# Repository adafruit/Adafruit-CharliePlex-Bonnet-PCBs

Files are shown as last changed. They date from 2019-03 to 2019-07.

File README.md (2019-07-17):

## Adafruit CharliePlex LED Matrix Bonnet PCB

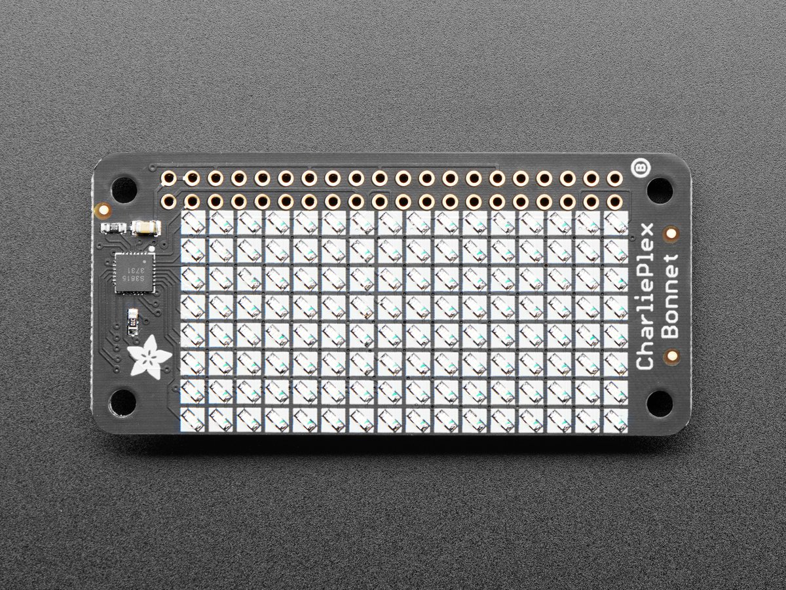
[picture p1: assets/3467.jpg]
<a href="http://www.adafruit.com/products/3467"><br/>
Click here to purchase one from the Adafruit shop</a>

PCB files for the Adafruit CharliePlex LED Matrix Bonnet. 

Format is EagleCAD schematic and board layout

* https://www.adafruit.com/?q=charlieplex%20bonnet

### Description

You won't be able to look away from the mesmerizing patterns created by this Adafruit CharliePlex LED Matrix Display Bonnet.  This 16x8 LED display can be placed atop any Raspberry Pi computer with a 2x20 connector, for a beautiful, bright grid of 128 charlieplexed LEDs. It even comes with a built-in charlieplex driver that is run over I2C.

We carry these Bonnets in a [few vivid colors](https://www.adafruit.com/?q=charlieplex%20bonnet)

What is particularly nice about this Wing is the I2C LED driver chip has the ability to PWM each individual LED in a 16x8 grid so you can have beautiful LED lighting effects, without a lot of pin twiddling. Simply tell the chip which LED on the grid you want lit, and what brightness and it's all taken care of for you. You get 8-bit (256 level) dimming for each individual LED.

The IS31FL3731 is a nice little chip - and it runs happily over 3.3V power. Inside is enough RAM for 8 separate frames of display memory so you can set up multiple frames of an animation and flip them to be displayed with a single command. Since it uses I2C, it takes up only the SDA/SCL pins on your Pi and can share those pins with other I2C devices and sensors.

Comes fully assembled, no soldering required, so you can plug it in immediately. To program it, [you'll use our CircuitPython library](https://github.com/adafruit/Adafruit_CircuitPython_IS31FL3731), which works with Linux computers like Raspberry Pi. After a pip install, [run some of the examples to display simple graphics or text.](https://github.com/adafruit/Adafruit_CircuitPython_IS31FL3731/tree/master/examples)

### License

Adafruit invests time and resources providing this open source design, please support Adafruit and open-source hardware by purchasing products from [Adafruit](https://www.adafruit.com)!

Designed by Limor Fried/Ladyada for Adafruit Industries.

Creative Commons Attribution/Share-Alike, all text above must be included in any redistribution. See license.txt for additional details.

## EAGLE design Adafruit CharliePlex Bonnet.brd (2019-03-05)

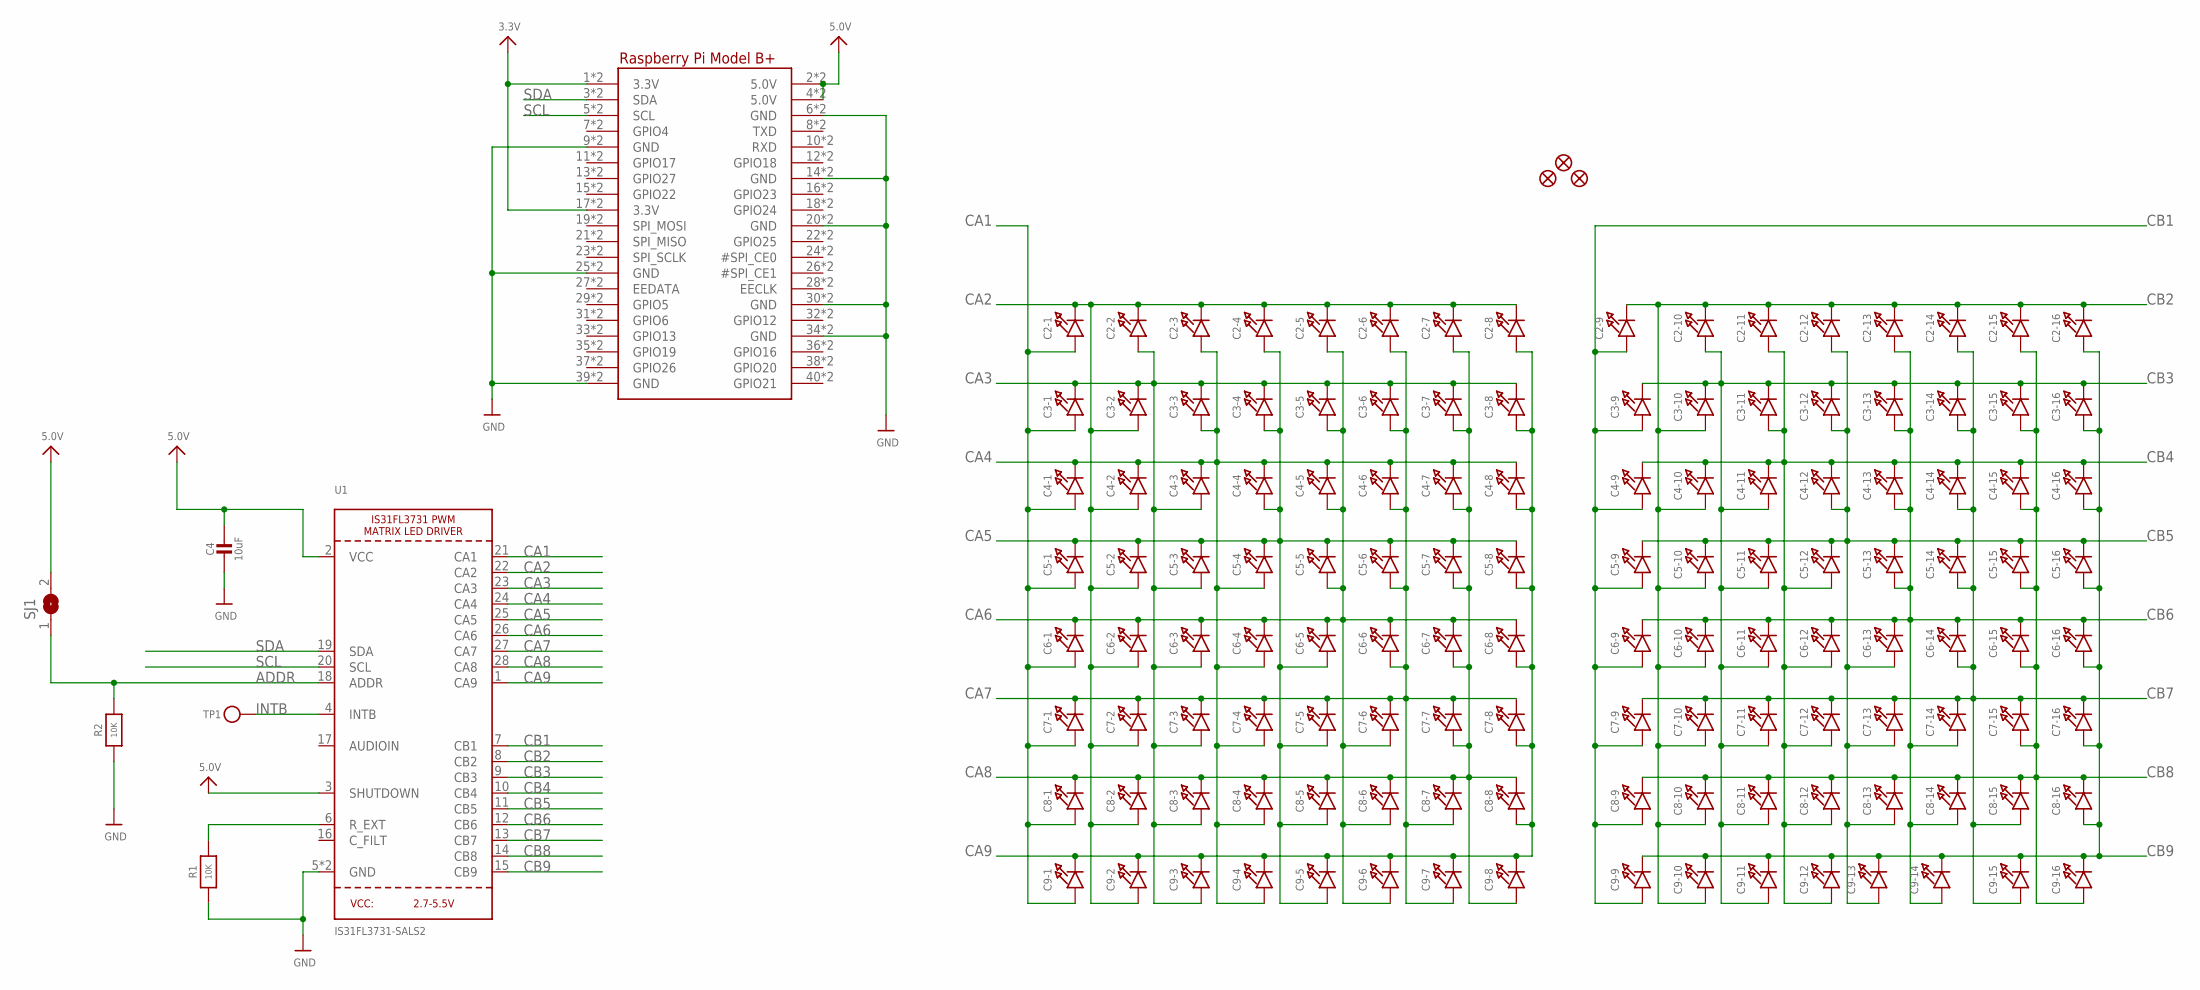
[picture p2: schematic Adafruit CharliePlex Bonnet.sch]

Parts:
C2-1, C2-2, C2-3, C2-4, C2-5, C2-6, C2-7, C2-8, C2-9, C2-10, C2-11, C2-12, C2-13, C2-14, C2-15, C2-16, C3-1, C3-2, C3-3, C3-4, C3-5, C3-6, C3-7, C3-8, C3-9, C3-10, C3-11, C3-12, C3-13, C3-14, C3-15, C3-16, C4-1, C4-2, C4-3, C4-4, C4-5, C4-6, C4-7, C4-8, C4-9, C4-10, C4-11, C4-12, C4-13, C4-14, C4-15, C4-16, C5-1, C5-2, C5-3, C5-4, C5-5, C5-6, C5-7, C5-8, C5-9, C5-10, C5-11, C5-12, C5-13, C5-14, C5-15, C5-16, C6-1, C6-2, C6-3, C6-4, C6-5, C6-6, C6-7, C6-8, C6-9, C6-10, C6-11, C6-12, C6-13, C6-14, C6-15, C6-16, C7-1, C7-2, C7-3, C7-4, C7-5, C7-6, C7-7, C7-8, C7-9, C7-10, C7-11, C7-12, C7-13, C7-14, C7-15, C7-16, C8-1, C8-2, C8-3, C8-4, C8-5, C8-6, C8-7, C8-8, C8-9, C8-10, C8-11, C8-12, C8-13, C8-14, C8-15, C8-16, C9-1, C9-2, C9-3, C9-4, C9-5, C9-6, C9-7, C9-8, C9-9, C9-10, C9-11, C9-12, C9-13, C9-14, C9-15, C9-16: LED0603_NOOUTLINE; CHIPLED_0603_NOOUTLINE
C4: 10uF; 0805-NO
FID1, FID2, FID3: FIDUCIAL_1MM
R1, R2: 10K; 0603-NO
RPI1: RASPBERRYPI_BPLUS_BONNET_THMSMT; PI_BONNET_THMSMT
SJ1: SOLDERJUMPER; SOLDERJUMPER_ARROW_NOPASTE
TP1: TESTPOINTROUND1.5MM; TESTPOINT_ROUND_1.5MM
U1: IS31FL3731-SALS2; QFN28_4MM_0.4MM

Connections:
3.3V: RPI1.1 (3.3V), RPI1.17 (3.3V), RPI1.S1 (3.3V), RPI1.S17 (3.3V)
5.0V: C4.1, RPI1.2 (5.0V), RPI1.4 (5.0V), RPI1.S2 (5.0V), RPI1.S4 (5.0V), SJ1.2, U1.2 (VCC), U1.3 (SHUTDOWN)
ADDR: R2.2, SJ1.1, U1.18 (ADDR)
CA1: C2-1.A, C3-1.A, C4-1.A, C5-1.A, C6-1.A, C7-1.A, C8-1.A, C9-1.A, U1.21 (CA1)
CA2: C2-1.C, C2-2.C, C2-3.C, C2-4.C, C2-5.C, C2-6.C, C2-7.C, C2-8.C, C3-2.A, C4-2.A, C5-2.A, C6-2.A, C7-2.A, C8-2.A, C9-2.A, U1.22 (CA2)
CA3: C2-2.A, C3-1.C, C3-2.C, C3-3.C, C3-4.C, C3-5.C, C3-6.C, C3-7.C, C3-8.C, C4-3.A, C5-3.A, C6-3.A, C7-3.A, C8-3.A, C9-3.A, U1.23 (CA3)
CA4: C2-3.A, C3-3.A, C4-1.C, C4-2.C, C4-3.C, C4-4.C, C4-5.C, C4-6.C, C4-7.C, C4-8.C, C5-4.A, C6-4.A, C7-4.A, C8-4.A, C9-4.A, U1.24 (CA4)
CA5: C2-4.A, C3-4.A, C4-4.A, C5-1.C, C5-2.C, C5-3.C, C5-4.C, C5-5.C, C5-6.C, C5-7.C, C5-8.C, C6-5.A, C7-5.A, C8-5.A, C9-5.A, U1.25 (CA5)
CA6: C2-5.A, C3-5.A, C4-5.A, C5-5.A, C6-1.C, C6-2.C, C6-3.C, C6-4.C, C6-5.C, C6-6.C, C6-7.C, C6-8.C, C7-6.A, C8-6.A, C9-6.A, U1.26 (CA6)
CA7: C2-6.A, C3-6.A, C4-6.A, C5-6.A, C6-6.A, C7-1.C, C7-2.C, C7-3.C, C7-4.C, C7-5.C, C7-6.C, C7-7.C, C7-8.C, C8-7.A, C9-7.A, U1.27 (CA7)
CA8: C2-7.A, C3-7.A, C4-7.A, C5-7.A, C6-7.A, C7-7.A, C8-1.C, C8-2.C, C8-3.C, C8-4.C, C8-5.C, C8-6.C, C8-7.C, C8-8.C, C9-8.A, U1.28 (CA8)
CA9: C2-8.A, C3-8.A, C4-8.A, C5-8.A, C6-8.A, C7-8.A, C8-8.A, C9-1.C, C9-2.C, C9-3.C, C9-4.C, C9-5.C, C9-6.C, C9-7.C, C9-8.C, U1.1 (CA9)
CB1: C2-9.A, C3-9.A, C4-9.A, C5-9.A, C6-9.A, C7-9.A, C8-9.A, C9-9.A, U1.7 (CB1)
CB2: C2-9.C, C2-10.C, C2-11.C, C2-12.C, C2-13.C, C2-14.C, C2-15.C, C2-16.C, C3-10.A, C4-10.A, C5-10.A, C6-10.A, C7-10.A, C8-10.A, C9-10.A, U1.8 (CB2)
CB3: C2-10.A, C3-9.C, C3-10.C, C3-11.C, C3-12.C, C3-13.C, C3-14.C, C3-15.C, C3-16.C, C4-11.A, C5-11.A, C6-11.A, C7-11.A, C8-11.A, C9-11.A, U1.9 (CB3)
CB4: C2-11.A, C3-11.A, C4-9.C, C4-10.C, C4-11.C, C4-12.C, C4-13.C, C4-14.C, C4-15.C, C4-16.C, C5-12.A, C6-12.A, C7-12.A, C8-12.A, C9-12.A, U1.10 (CB4)
CB5: C2-12.A, C3-12.A, C4-12.A, C5-9.C, C5-10.C, C5-11.C, C5-12.C, C5-13.C, C5-14.C, C5-15.C, C5-16.C, C6-13.A, C7-13.A, C8-13.A, C9-13.A, U1.11 (CB5)
CB6: C2-13.A, C3-13.A, C4-13.A, C5-13.A, C6-9.C, C6-10.C, C6-11.C, C6-12.C, C6-13.C, C6-14.C, C6-15.C, C6-16.C, C7-14.A, C8-14.A, C9-14.A, U1.12 (CB6)
CB7: C2-14.A, C3-14.A, C4-14.A, C5-14.A, C6-14.A, C7-9.C, C7-10.C, C7-11.C, C7-12.C, C7-13.C, C7-14.C, C7-15.C, C7-16.C, C8-15.A, C9-15.A, U1.13 (CB7)
CB8: C2-15.A, C3-15.A, C4-15.A, C5-15.A, C6-15.A, C7-15.A, C8-9.C, C8-10.C, C8-11.C, C8-12.C, C8-13.C, C8-14.C, C8-15.C, C8-16.C, C9-16.A, U1.14 (CB8)
CB9: C2-16.A, C3-16.A, C4-16.A, C5-16.A, C6-16.A, C7-16.A, C8-16.A, C9-9.C, C9-10.C, C9-11.C, C9-12.C, C9-13.C, C9-14.C, C9-15.C, C9-16.C, U1.15 (CB9)
GND: C4.2, R1.1, R2.1, RPI1.6 (GND), RPI1.9 (GND), RPI1.14 (GND), RPI1.20 (GND), RPI1.25 (GND), RPI1.30 (GND), RPI1.34 (GND), RPI1.39 (GND), RPI1.S6 (GND), RPI1.S9 (GND), RPI1.S14 (GND), RPI1.S20 (GND), RPI1.S25 (GND), RPI1.S30 (GND), RPI1.S34 (GND), RPI1.S39 (GND), U1.5 (GND), U1.THERMAL (GND)
INTB: TP1.P$1, U1.4 (INTB)
R_EXT: R1.2, U1.6 (R_EXT)
SCL: RPI1.5 (SCL), RPI1.S5 (SCL), U1.20 (SCL)
SDA: RPI1.3 (SDA), RPI1.S3 (SDA), U1.19 (SDA)

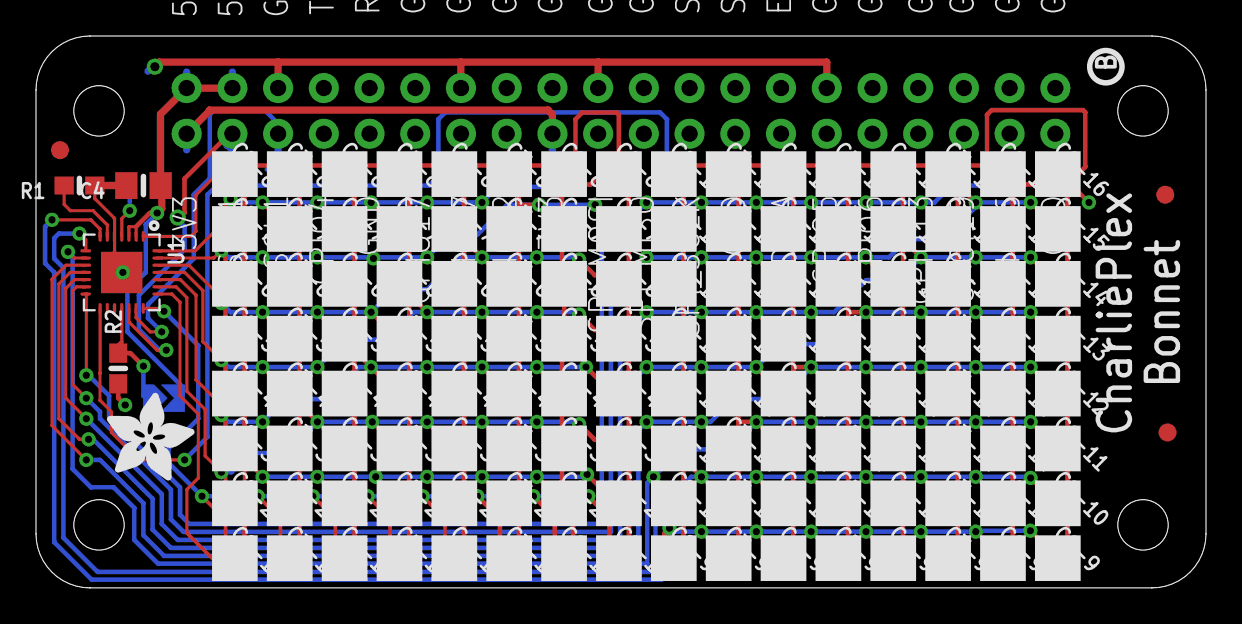
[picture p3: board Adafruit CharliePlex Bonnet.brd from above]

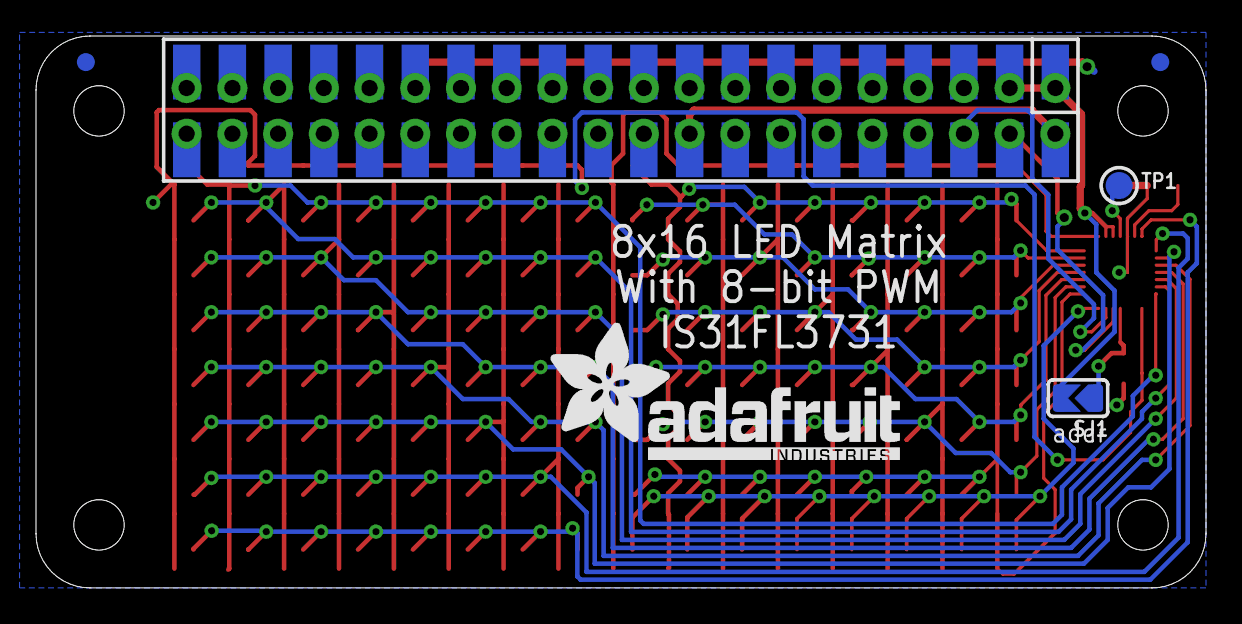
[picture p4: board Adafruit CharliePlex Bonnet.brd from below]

Board: 2 copper layers, 65.0 x 30.7 mm, 142 parts (3 on the bottom side), 26 nets.

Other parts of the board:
U$1: ADAFRUIT_5MM
U$2: ADAFRUIT_TEXT_20MM
U$13: CHARLIE_BONNET_GRID
U$14: PCBFEAT-REV-040

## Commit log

2019-03-05 adding PCB files
    [Adafruit CharliePlex Bonnet.brd, Adafruit CharliePlex Bonnet.sch]
2019-07-17 updated to use cookiecutter for pcb repos

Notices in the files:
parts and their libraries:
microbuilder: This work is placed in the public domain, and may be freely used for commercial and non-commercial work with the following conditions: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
